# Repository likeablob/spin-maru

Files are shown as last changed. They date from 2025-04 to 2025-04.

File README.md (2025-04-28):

# spin-maru

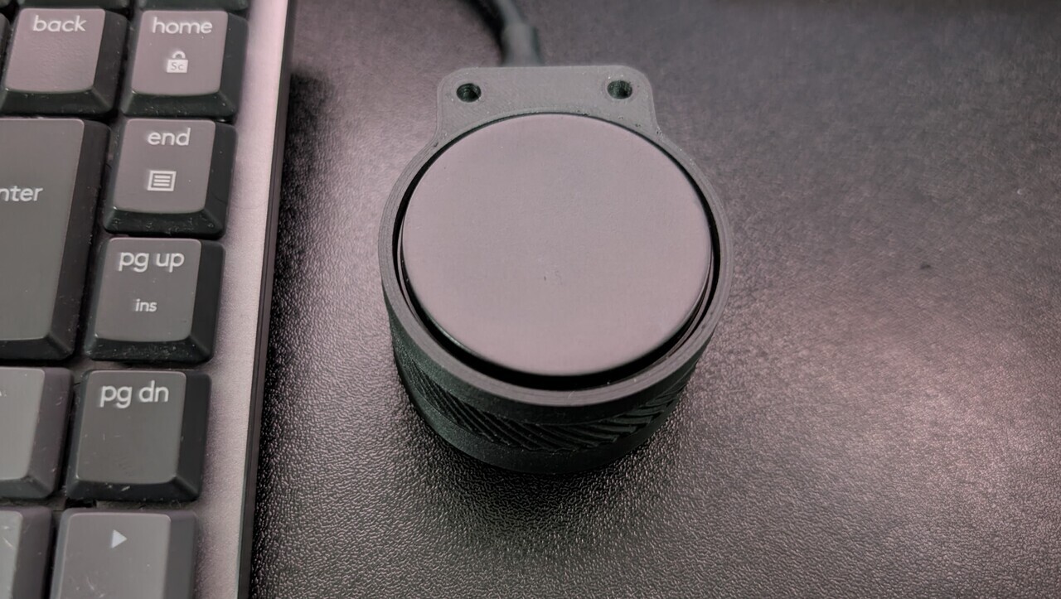
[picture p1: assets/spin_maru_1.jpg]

<video src="https://github.com/user-attachments/assets/ebdbabc0-5cc7-43a6-a732-e8d0603426d6" height="200px" autoplay loop muted playsinline></video>

Spin-maru is a custom input device with a circular touchpad and a free-spinning scroll wheel.

- Cirque 35mm round touchpad module.
- Free-spinning wheel on a ball bearing, monitored by a high-resolution magnetic encoder (AS5600).
- QMK-based firmware with [high-resolution scrolling support](https://github.com/qmk/qmk_firmware/pull/24423).
- Customizable 3D Printed Enclosure designed in OpenSCAD.

## BOM

| Component | Quantity | Notes |
| :--- | :--- | :--- |
| Seeed XIAO RP2040 | 1 | |
| Cirque GlidePoint Circle Trackpad 35mm Round SPI/I2C curved overlay | 1 | [TM035035-2024-003](https://www.mouser.com/ProductDetail/Cirque/TM035035-2024-003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) |
| AS5600 Magnetic Rotary Encoder Module  (w/ magnet) | 1 | 23.5x22.5 mm |
| 696ZZ Ball Bearing | 1 | [Eastern Seiko 15ST6B1.5](https://www.easternseiko.co.jp/products/product_j.html) |
| 6 x 6 mm Tactile Switch | 1 | |
| 5.5 mm Tungsten Lure Weight | 8 | Zappu lure weight |
| M2 x 8mm Self-tapping Screws | 2 | |
| Anti-slip Sheet (Optional) | 1 | |
| Φ3mm x 6mm Neodymium Magnets (Optional) | 3 | |
| Wire | - | |
| LOCTITE | - | |

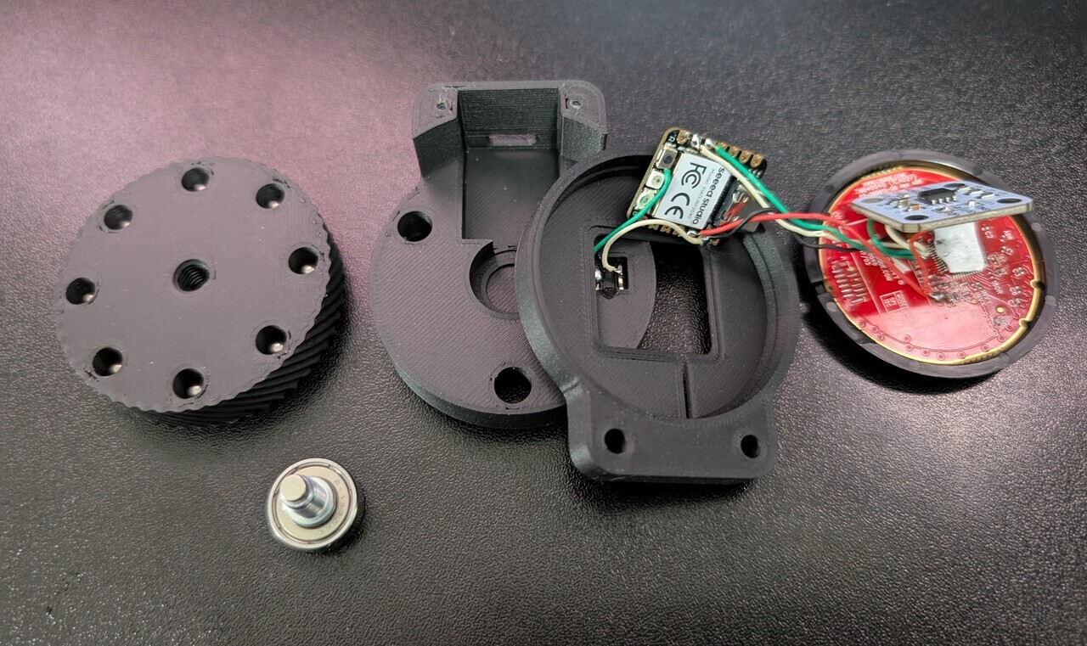
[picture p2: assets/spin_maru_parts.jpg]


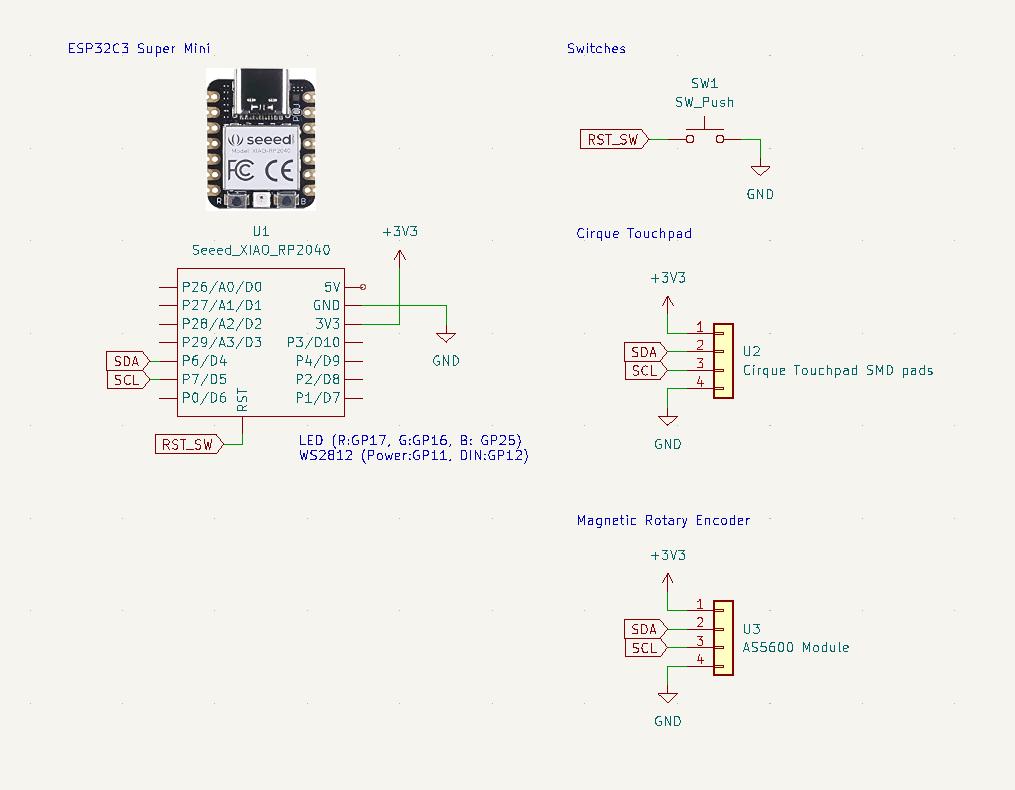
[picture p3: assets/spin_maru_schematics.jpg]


## 3D Printed Parts

- All necessary STL and OpenSCAD files can be found in the [`./enclosure`](./enclosure/) directory.

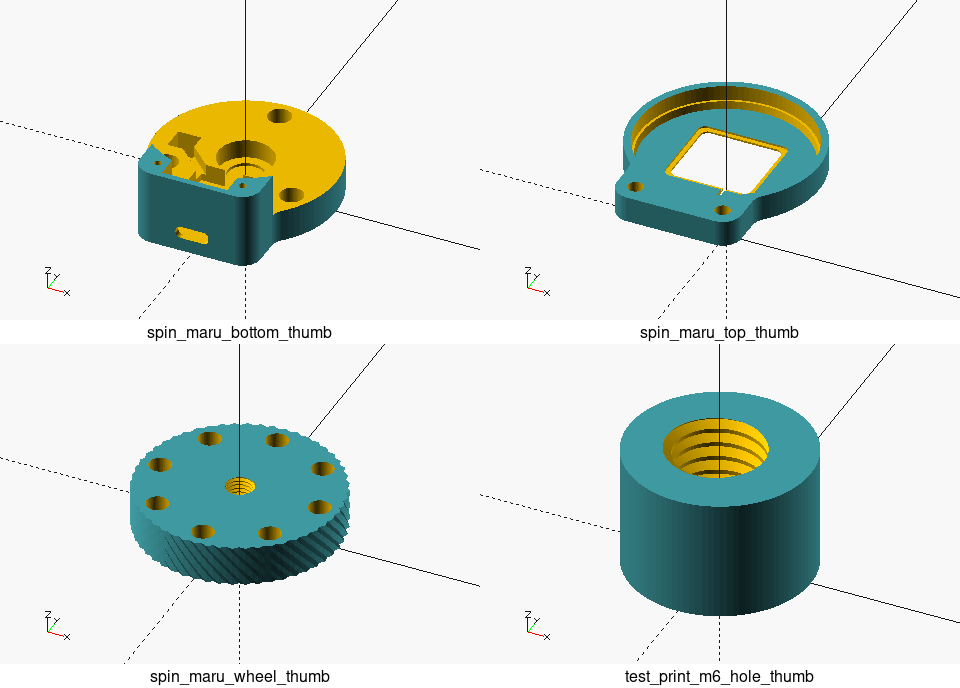
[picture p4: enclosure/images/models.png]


## Firmware

- This device uses QMK firmware. Install [QMK CLI](https://docs.qmk.fm/cli) and set up the environment first.
- Firmware source: [likeablob/spin-maru](https://github.com/likeablob/qmk_firmware/tree/likeablob/spin-maru)

```sh
# Clone the firmware repository
$ git clone --depth 1 --recursive --shallow-submodules -b likeablob/spin-maru https://github.com/likeablob/qmk_firmware
$ cd qmk_firmware

# Put the XIAO RP2040 into bootloader mode the first time:
# Hold the BOOT button, press the RESET button, then release BOOT.
# Or, connect while holding BOOT. It should appear as a USB drive (RPI-RP2).
# If using Linux, you might need to mount it (e.g., using udisksctl):
# $ udisksctl mount -b /dev/disk/by-label/RPI-RP2
$ qmk flash -kb likeablob/spin_maru -km default

# For subsequent flashes:
# Double-click the bottom reset switch quickly to enter bootloader mode.
# Then, run the 'qmk flash' command again.
```

## Photos

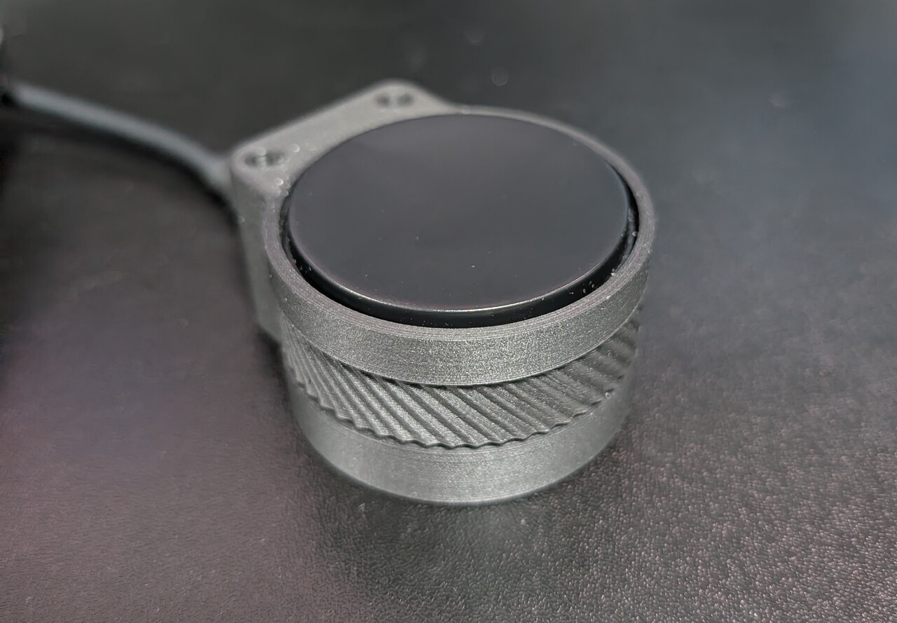
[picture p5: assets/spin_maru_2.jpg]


<video src="https://github.com/user-attachments/assets/ac635eaa-d613-44cf-9fdc-b7874c3f3494" height="200px" autoplay loop muted playsinline></video>

## License

MIT

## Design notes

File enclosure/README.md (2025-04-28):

# spin-maru/enclosure

## Prerequisites

- OpenSCAD (nightly build) 2025.02
- GNU Make
- ImageMagick
- BOSL2 (included as a submodule)

## Build

```sh
$ git submodule update --init --recursive

# Generate .scad and .stl files.
$ make all -B

# Generate thumbnail images.
$ make images -B
```

## Parts

| Preview | STL |
| --- | --- |
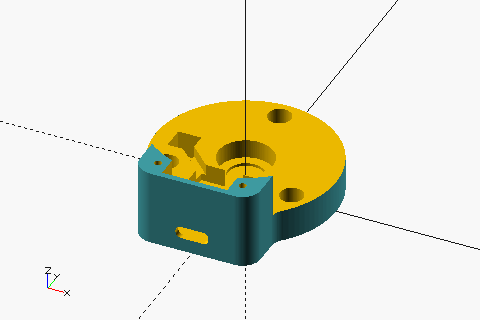
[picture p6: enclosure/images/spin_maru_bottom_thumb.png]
|  | [spin_maru_bottom.stl](./spin_maru_bottom.stl) |
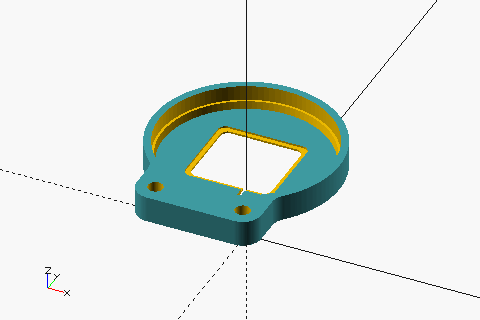
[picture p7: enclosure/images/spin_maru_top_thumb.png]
|  | [spin_maru_top.stl](./spin_maru_top.stl) |
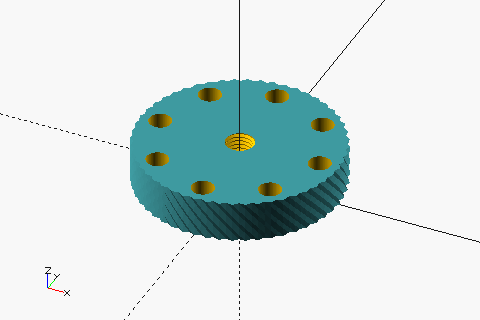
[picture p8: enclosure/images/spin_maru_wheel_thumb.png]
|  | [spin_maru_wheel.stl](./spin_maru_wheel.stl) |
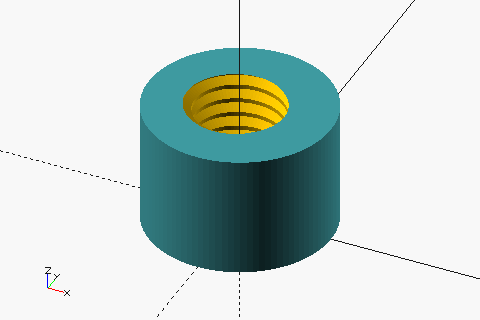
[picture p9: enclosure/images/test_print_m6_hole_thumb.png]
|  | [test_print_m6_hole.stl](./test_print_m6_hole.stl) |

## Print conditions

- 1.75mm PLA
- 0.2mm layer height

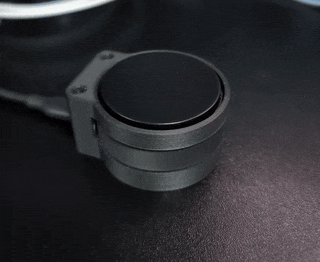
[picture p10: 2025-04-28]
assets/spin_maru_1.gif

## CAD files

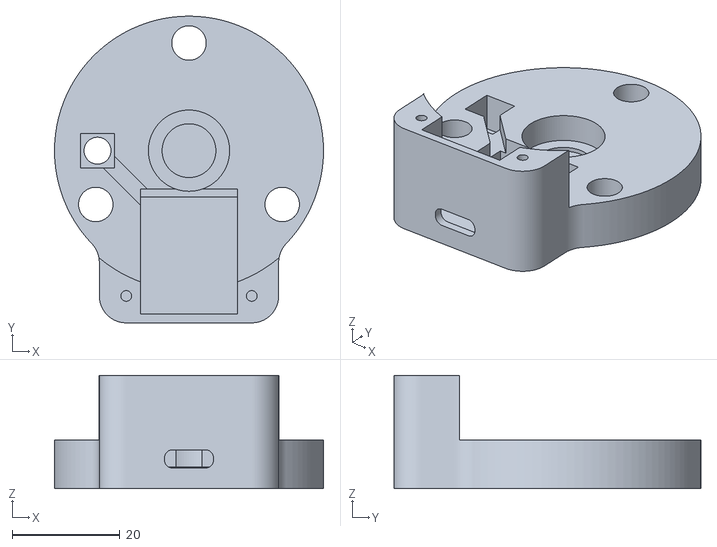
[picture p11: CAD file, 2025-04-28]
enclosure/spin_maru_bottom.stl
50.0 x 57.0 x 21.0

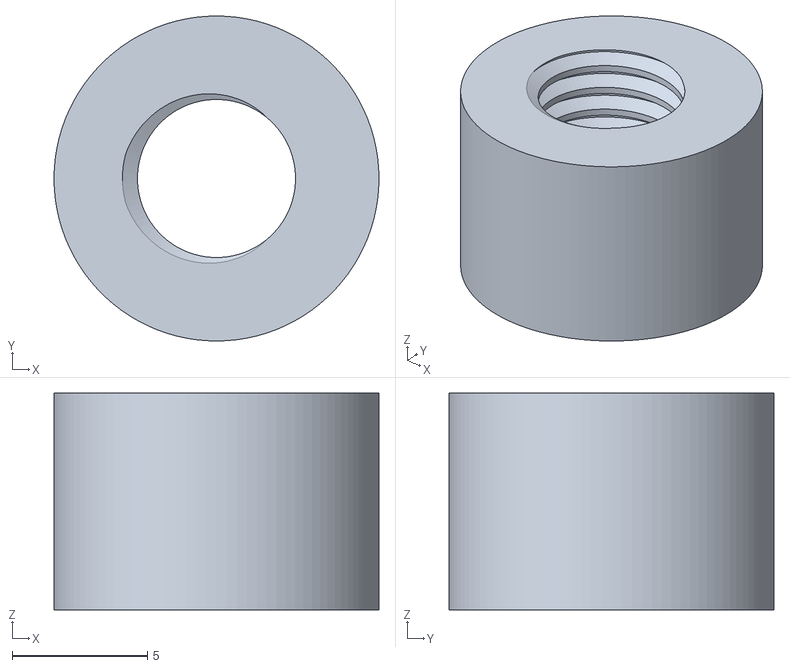
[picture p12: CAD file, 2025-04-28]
enclosure/test_print_m6_hole.stl
12.0 x 12.0 x 8.00

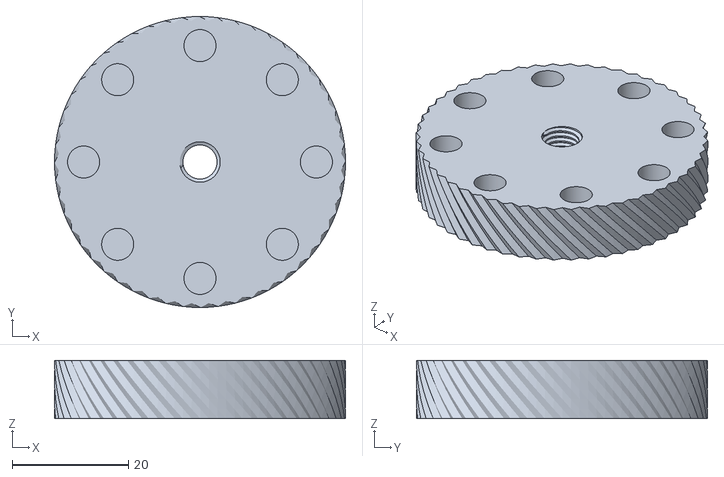
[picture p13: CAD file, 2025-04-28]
enclosure/spin_maru_wheel.stl
50.0 x 50.0 x 10.0

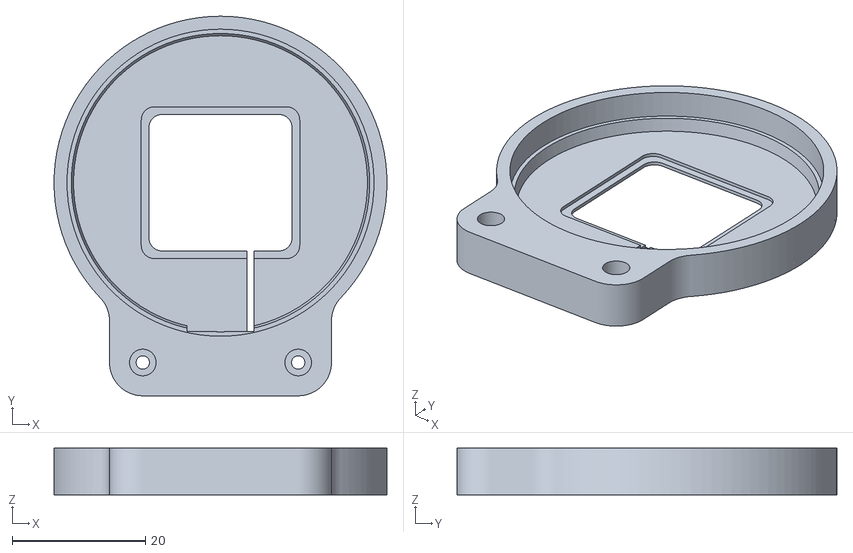
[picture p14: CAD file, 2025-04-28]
enclosure/spin_maru_top.stl
50.0 x 57.0 x 7.00

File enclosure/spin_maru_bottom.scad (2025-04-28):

include <lib/spin_maru.scad>

$fn = 100;

spin_maru_bottom();

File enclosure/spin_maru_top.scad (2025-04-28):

include <lib/spin_maru.scad>

$fn = 100;

spin_maru_top();

% pos_wheel() spin_maru_wheel();
% spin_maru_bottom();

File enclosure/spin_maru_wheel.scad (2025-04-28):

include <lib/spin_maru.scad>

$fn = 100;

spin_maru_wheel();

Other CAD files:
enclosure/test_print_m6_hole.scad
